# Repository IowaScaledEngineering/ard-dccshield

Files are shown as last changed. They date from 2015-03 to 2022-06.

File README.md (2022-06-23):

# About the ARD-DCCSHIELD

The ARD-DCCSHIELD is an optoisolated interface shield for connecting an Arduino to a model railroad DCC control system.  Additionally, the board has provisions for connecting I2C accessories and general purpose I/O lines, as well as optionally (jumper selectably) powering the Arduino off of DCC power and providing up to 400mA of 5VDC to connected circuitry.

The board is designed to be compatible with various DCC decoder libraries and Arduino boards.  We typically use [Alex Shepherd's excellent NmraDcc library](https://github.com/mrrwa/NmraDcc/).  

The ARD-DCCSHIELD was designed by Nathan Holmes (maverick /at/ drgw.net) and Michael Petersen (railfan /at/ drgw.net).  The ARD-DCCSHIELD is open hardware, meaning that anyone is welcome to make their own or change/improve upon our design to meet their needs.  Please refer to the hardware and software license files in this repository for details.

For those not wanting to build their own, the boards are [available for purchase](http://www.iascaled.com/store/ARD-DCCSHIELD) from Iowa Scaled Engineering.

## Features

* Convenient way to interface standard Arduinos with DCC track signals, in order to build custom decoders
* Can route DCC signal to D2, D3, or D7 as an input, depending on the needs of the host processor
* Provides complete electrical isolation between the track and your Arduino/computer (if not powered off DCC)
* Can provide up to 500mA of 5V DC power off the DCC track signal
* Provides handy Qwiic-compatible I2C port for connecting more peripherals (v2.x only)
* Provides 8-position terminal block for connecting to Arduino I/O lines

## Getting Started

At the bare minimum, you'll need to:
 * Have a working knowledge of electronics and programming.  The ARD-DCCSHIELD is a building block that provides an electrical interface between an Arduino and the DCC track signal, not a complete decoder.
 * Connect DCC track voltage should be connected to the DCC connector, a blue two-pin terminal block at the bottom of the board (J7 on v1.x boards, J6 on v2.x)
 * Configure the board to route the DCC signal to the appropriate Arduino digital I/O pin (D2, D3, or D7).  With v1.x boards, this was done using JP4 and possibly JP2, pins 1-2).  With v2.x boards, this just involves flipping one of the DIP switches (SW1, switches 3-5) to "ON" matching the pin you want to route the signal into.
 * Provide power to the Arduino or configure the DCCSHIELD to power things off of DCC (JP5 on v1.x boards, the small slide switch SW2 on v2.x boards).

You'll also probably need to [install an Arduino library](https://www.arduino.cc/en/Guide/Libraries) to decode the DCC signal, unless you intend to write your own.

If all is good, you'll get both a green and an amber LED glowing on the shield.

When in doubt, please refer to the schematic.  The source files are in gEDA format, but there are PDFs of the production version schematics under the pg/ directory.  Just pick the version that corresponds to your PCB version and open the "ard-dccshield.pdf" file.

 * [v1.0 Schematic](https://github.com/IowaScaledEngineering/ard-dccshield/raw/master/pg/ard-dccshield-v1.0-ba9ec04/ard-dccshield.pdf)
 * [v1.1 Schematic](https://github.com/IowaScaledEngineering/ard-dccshield/raw/master/pg/ard-dccshield-v1.1-f6d6da8/ard-dccshield.pdf)
 * [v1.2 Schematic](https://github.com/IowaScaledEngineering/ard-dccshield/raw/master/pg/ard-dccshield-v1.2-2bd1af7/ard-dccshield.pdf)
 * [v1.3 Schematic](https://github.com/IowaScaledEngineering/ard-dccshield/raw/master/pg/ard-dccshield-v1.3-e23d249/ard-dccshield.pdf)
 * [v2.0 Schematic](https://github.com/IowaScaledEngineering/ard-dccshield/raw/master/pg/ard-dccshield-v2.0-4f6f1bd/ard-dccshield.pdf)

## Indicators

### D1 - Amber LED
The amber LED indicates that a signal is present on J6 (v2.x boards) or J7 (v1.x boards), the DCC input.  If the amber LED does not light, the board is not receiving a signal.

### D2 - Green LED
The green LED indicates that the ARD-DCCSHIELD is correctly powered.  If this light does not come on, check that either the Arduino is getting power from an external source or that the power switch SW2 (v2.x boards) or JP5 (v1.x boards)is set correctly.

## Connectors - Version 2.x Boards ONLY

*Version 2.x is the most recent revision of the ARD-DCCSHIELD.  All boards shipped by ISE after 6/15/2022 will be version 2.0 or later.*

### J1/J2 - Standard Rev 3 Arduino Headers

These are the big pin headers that connect the shield through to an Arduino.  

For some early Arduinos (pre-R3 pinout), you'll notice that the topmost pins (N/C, VIO, RST, 3.3V on J1, SCL, SDA, AREF, and GND on J2) do not connect.  See the JP6 entry in the Configuration section below for details on what you'll need to do.

### J3 - Holes for Arduino SPI

If you need to pass the 6-pin ICSP/SPI header through the ARD-DCCSHIELD to some other shield above it, we've left holes in the right spot.  You'll need to solder in an appropriate 2x3 pin header - see the bill of materials for a suggested Samtec part number.  These holes are not connected to anything on the ARD-DCCSHIELD.

### J4 - Digital I/O Terminal Block

Since most folks are going to decode a DCC signal to then trigger some other hardware, we've provided terminal blocks for eight of the Arduino I/O pins.  These connect to the digital I/O corresponding to the label except for D14, which connects to A0.

### J5 - Power and VIO

Most external hardware is going to need access to power and ground.  J5 provides access to the Arduino +5V line, ground, and VIO (the Arduino's native I/O voltage).

### J6 - DCC Input

This 2-position blue terminal block expects a DCC signal in the range of track voltage (9-22V).  Depending on track voltage, this will present a 9-20mA load to your booster.

### J7 - Qwiic-Compatible I2C Port

This connector is compatible with [SparkFun's Qwiic connector standard](https://www.sparkfun.com/qwiic) for I2C peripherals.  The signals here have been level-shifted to 3.3V for compatibility.  If you want to use an I2C peripheral operating at the Arduino's native VIO (5V with most AVR-based Arduinos, 3.3V with most ARM-based Arduinos), tap the signals out of J8 instead.

### J8 - Alternate 4-Pin I2C

This connector provides an alternate pinout for I2C connections.   These pins are ***not*** level shifted, and operate at the native VIO voltage of the Arduino (5V with most AVR-based Arduinos, 3.3V with most ARM-based Arduinos).

## Configuration - Version 2.x Boards ONLY

### SW1 - Configuration DIP Switch
* Switch 1 does nothing (not connected)
* Switch 2 connects the DCC acknowledgement current pulse generator (ACK) circuit to Arduino pin A1 if switched on.  This will allow the shield to emit a 60mA DCC programming acknowledgement pulse when pin A1 is set high.  The ACK circuit is not designed to operate continually, but only for the ~6 millisecond pulses needed for generating ACKs.  While it should protect itself, U4 and R8 will become quite hot if A1 remains high for significant lengths of time.  If left off, it will disable the ACK generator. 
* Switch 3 routes the incoming DCC signal to Arduino pin D2 if on
* Switch 4 routes the incoming DCC signal to Arduino pin D3 if on
* Switch 5 routes the incoming DCC signal to Arduino pin D7 if on

### SW2 - Power Supply Selection
If SW2 is set towards "ISOLATED", the Arduino is galvanically isolated from track power and can be safely connected to any other power source.  (In fact, it *must* be powered from some other source.)  This allows it to operate connected to an auxiliary power bus or other such power source that you don't want shorted to track power.

If SW2 is set towards "FROM DCC", the ARD-DCCSHIELD will use an onboard high efficiency DC-DC converter to convert track power into 5V to power the Arduino through the 5V pin, as well as the ARD-DCCSHIELD and any other attached hardware.  The power supply is good for 500mA.  Typically the Arduino and the ARD-DCCSHIELD will need 40-50mA of that, so you can safely power approximately 400mA of additional 5V load off of the regulator as well.

### JP6 - Power Supply Selection

Normally, the ARD-DCCSHIELD gets its power from the VIO pin, so as to be compatible with both 3.3V and 5V Arduino-format boards.  For early Arduino pinouts (now exceedingly rare) that lack a VIO (I/O voltage) pin, there's solder jumper JP6 which shorts the VIO line (which isn't present) to 5V.  You'll need to solder jumper JP6 closed to allow the shield to work correctly.  Just heat the pads and apply a small amount of solder to bridge the two halves.  

*Note:  Once JP6 is shorted, the board will fry any 3.3V Arduino it gets plugged into.  Be very careful.  If you want to use the board with a low voltage Arduino once again, carefully remove the solder bridge with solder braid or similar.*

---
# Documentation for v1.x ARD-DCCSHIELD Boards

*Version 1.x is the first generation of the ARD-DCCSHIELD.  The documentation is preserved here for reference, and will apply to all boards shipped by ISE before 6/15/2022.*

## Configuration - Version 1.x Boards ONLY

### JP1 - I2C Pull-Up Resistors

I2C is an open-collector bus, meaning each node can only pull the line low.  Therefore, both SDA and SCL must be pulled up with resistors to make the bus function.  If you intend to use the I2C connections on the ARD-DCCSHIELD and don't have pull-ups elsewhere, jumper pins 1-2 and 3-4 of JP1 to provide 2k pull-ups on both SDA and SCL.

### JP2 (Pins 1-2) - I2C /IORST

If you need power on the [Iowa Scaled Engineering standard I2C 6p6c (RJ11) connector](https://www.iascaled.com/store/6P6C-I2C), it's typically sent down the /IORST line.  Jumpering pins 1-2 will connect VIO on the Arduino/shield to the /IORST line on the connector (pin 4).  If you don't intend to use I2C or don't need power, leave this jumper open.

Alternately, if you're not using Arduino D7 for your DCC signal (see JP4 configuration below) and want the ability to reset I2C peripherals using this signal, you can tie /IORST to D7 by placing the number between pins 2-3.

### JP3 - I2C /INT and /OE 

The [Iowa Scaled Engineering standard I2C 6p6c (RJ11) connector](https://www.iascaled.com/store/6P6C-I2C) allows for two additional signals: /OE (active low Output Enable) going from the Arduino to the I2C bus; and /INT (active low interrupt), to allow I2C slaves to signal the Arduino they need attention.  Jumper JP3 pins 1-2 to connect /INT to Arduino pin D6 and/or JP3 pins 3-4 to connect /OE to Arduino pin D5.

### JP4 and JP2 (Pins 3-4) - DCC Signal to Arduino Pin

Probably the single most important configuration on the ARD-DCCSHIELD is to select which Arduino pin will receive the DCC signal.  Typically this is going to be a pin that can be conencted to a hardware change interrupt in the code, as edges need to be precisely detected to decode the signal correctly.  To accomodate a wide variety of Arduinos, there are three possible selections:
 * DCC signal to D2 - jumper JP4, pins 3-4
 * DCC signal to D3 - jumper JP4, pins 1-2
 * DCC signal to D7 - jumper JP2, pins 3-4

A complete list of which digital IO lines are available as hardware interrupts is available at the Arduino [attachInterrupt()](https://www.arduino.cc/en/Reference/AttachInterrupt) page.

### JP5 - Arduino Powered from DCC

If JP5 is left un-jumpered, the Arduino is galvanically isolated from track power and can be safely connected to any other power source.  (In fact, it *must* be powered from some other source.)  This allows it to operate connected to an auxilliary power bus or other such power source that you don't want shorted to track power.

If pins 1-2 and 3-4 of JP5 are jumpered, the ARD-DCCSHIELD will use an onboard high efficiency DC-DC converter to convert track power into 5V to power the Arduino, ARD-DCCSHIELD, and any other attached hardware.  The power supply is good for 500mA.  Typically the Arduino and the ARD-DCCSHIELD will need 40-50mA of that, so you can safely power approximately 400mA of additional 5V load off of the regulator as well.

### JP6 - Boards without VIO

Normally, the ARD-DCCSHIELD gets its power from the VIO pin, so as to be compatible with both 3.3V and 5V Arduino-format boards.  For early Arduino pinouts that lack a VIO (I/O voltage) pin, there's solder jumper JP6 which shorts the VIO line (which isn't present) to 5V.  You'll need to solder jumper JP6 closed to allow the shield to work correctly.  Just heat the pads and apply a small amount of solder to bridge the two halves.  

*Note:  Once JP6 is shorted, the board will fry any 3.3V Arduino it gets plugged into.  Be very careful.  If you want to use the board with a low voltage Arduino once again, carefully remove the solder bridge with solder braid or similar.*

### JP7 - Enable Programming ACK

Jumpering pins 1-2 & 3-4 of JP7 will allow the shield to emit a 60mA DCC programming acknowledgement pulse when pin .  The ACK circuit is connected to Arduino pin A1, and will generate an ACK current pulse when A1 is set high.  The ACK circuit is not designed to operate continually, but only for the ~6 millisecond pulses needed for generating ACKs.  While it should protect itself, U4 and R8 will become quite hot if A1 remains high for significant lengths of time.

## Connectors - Version 1.x Boards ONLY

*Version 1.x is the first generation of the ARD-DCCSHIELD.  The documentation is preserved here for reference, and will apply to all boards shipped by ISE before 6/15/2022.*

### J1/J2 - Standard Rev 3 Arduino Headers

These are the big pin headers that connect the shield through to an Arduino.  

For some early Arduinos, you'll notice that the topmost pins (N/C, VIO, RST, 3.3V on J1, SCL, SDA, AREF, and GND on J2) do not connect.  See the JP6 entry in the Configuration section below for details on what you'll need to do.

### J3 - Holes for Arduino SPI

If you need to pass the 6-pin ICSP/SPI header through the ARD-DCCSHIELD to some other shield above it, we've left holes in the right spot.  You'll need to solder in an appropriate 2x3 pin header - see the bill of materials for a suggested Samtec part number.  These holes are not connected to anything on the ARD-DCCSHIELD.

### J4 - Digital I/O Terminal Block

Since most folks are going to decode a DCC signal to then trigger some other hardware, we've provided terminal blocks for eight of the Arduino I/O pins.  These connect to the digital I/O corresponding to the label except for D14, which connects to A0.

### J5 - Power and VIO

Most external hardware is going to need access to power and ground.  J5 provides access to the Arduino +5V line, ground, and VIO (the Arduino's native I/O voltage).

### J6 - ISE Standard 6p6c I2C 

This is an [Iowa Scaled Engineering standard I2C 6p6c (RJ11) connector](https://www.iascaled.com/store/6P6C-I2C), which can be used to connect to a number of ISE I2C peripheral boards.  It provides a handy modular plug for the I2C bus.

### J7 - DCC Input

This expects a DCC signal in the range of track voltage (9-22V).  Depending on track voltage, this will present a 9-20mA load to your booster.

### J8 - Alternate 4-Pin I2C

This connector provides an alternate pinout for I2C connections. 
*Note:  On rev 1.1 of the PCB, the SDA and SCL silkscreen markings are reversed.*

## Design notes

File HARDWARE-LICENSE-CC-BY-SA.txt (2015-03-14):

The hardware design files for the Iowa Scaled Engineering ARD-DCCSHIELD are
open hardware, and licensed under the Creative Commons Attribution-Share
Alike license.

A copy can be found below, or from 
  http://creativecommons.org/licenses/by-sa/4.0/legalcode
-----------------------------------------------------------------------------

Creative Commons Attribution-ShareAlike 4.0 International Public License

By exercising the Licensed Rights (defined below), You accept and agree to
be bound by the terms and conditions of this Creative Commons
Attribution-ShareAlike 4.0 International Public License ("Public License").
To the extent this Public License may be interpreted as a contract, You are
granted the Licensed Rights in consideration of Your acceptance of these
terms and conditions, and the Licensor grants You such rights in
consideration of benefits the Licensor receives from making the Licensed
Material available under these terms and conditions.

Section 1 – Definitions.

    Adapted Material means material subject to Copyright and Similar Rights
that is derived from or based upon the Licensed Material and in which the
Licensed Material is translated, altered, arranged, transformed, or
otherwise modified in a manner requiring permission under the Copyright and
Similar Rights held by the Licensor. For purposes of this Public License,
where the Licensed Material is a musical work, performance, or sound
recording, Adapted Material is always produced where the Licensed Material
is synched in timed relation with a moving image.
    Adapter's License means the license You apply to Your Copyright and
Similar Rights in Your contributions to Adapted Material in accordance with
the terms and conditions of this Public License.
    BY-SA Compatible License means a license listed at
creativecommons.org/compatiblelicenses, approved by Creative Commons as
essentially the equivalent of this Public License.
    Copyright and Similar Rights means copyright and/or similar rights
closely related to copyright including, without limitation, performance,
broadcast, sound recording, and Sui Generis Database Rights, without regard
to how the rights are labeled or categorized. For purposes of this Public
License, the rights specified in Section 2(b)(1)-(2) are not Copyright and
Similar Rights.
    Effective Technological Measures means those measures that, in the
absence of proper authority, may not be circumvented under laws fulfilling
obligations under Article 11 of the WIPO Copyright Treaty adopted on
December 20, 1996, and/or similar international agreements.
    Exceptions and Limitations means fair use, fair dealing, and/or any
other exception or limitation to Copyright and Similar Rights that applies
to Your use of the Licensed Material.
    License Elements means the license attributes listed in the name of a
Creative Commons Public License. The License Elements of this Public License
are Attribution and ShareAlike.
    Licensed Material means the artistic or literary work, database, or
other material to which the Licensor applied this Public License.
    Licensed Rights means the rights granted to You subject to the terms and
conditions of this Public License, which are limited to all Copyright and
Similar Rights that apply to Your use of the Licensed Material and that the
Licensor has authority to license.
    Licensor means the individual(s) or entity(ies) granting rights under
this Public License.
    Share means to provide material to the public by any means or process
that requires permission under the Licensed Rights, such as reproduction,
public display, public performance, distribution, dissemination,
communication, or importation, and to make material available to the public
including in ways that members of the public may access the material from a
place and at a time individually chosen by them.
    Sui Generis Database Rights means rights other than copyright resulting
from Directive 96/9/EC of the European Parliament and of the Council of 11
March 1996 on the legal protection of databases, as amended and/or
succeeded, as well as other essentially equivalent rights anywhere in the
world.
    You means the individual or entity exercising the Licensed Rights under
this Public License. Your has a corresponding meaning.

Section 2 – Scope.

    License grant.
        Subject to the terms and conditions of this Public License, the
Licensor hereby grants You a worldwide, royalty-free, non-sublicensable,
non-exclusive, irrevocable license to exercise the Licensed Rights in the
Licensed Material to:
            reproduce and Share the Licensed Material, in whole or in part;
and
            produce, reproduce, and Share Adapted Material.
        Exceptions and Limitations. For the avoidance of doubt, where
Exceptions and Limitations apply to Your use, this Public License does not
apply, and You do not need to comply with its terms and conditions.
        Term. The term of this Public License is specified in Section 6(a).
        Media and formats; technical modifications allowed. The Licensor
authorizes You to exercise the Licensed Rights in all media and formats
whether now known or hereafter created, and to make technical modifications
necessary to do so. The Licensor waives and/or agrees not to assert any
right or authority to forbid You from making technical modifications
necessary to exercise the Licensed Rights, including technical modifications
necessary to circumvent Effective Technological Measures. For purposes of
this Public License, simply making modifications authorized by this Section
2(a)(4) never produces Adapted Material.
        Downstream recipients.
            Offer from the Licensor – Licensed Material. Every recipient of
the Licensed Material automatically receives an offer from the Licensor to
exercise the Licensed Rights under the terms and conditions of this Public
License.
            Additional offer from the Licensor – Adapted Material. Every
recipient of Adapted Material from You automatically receives an offer from
the Licensor to exercise the Licensed Rights in the Adapted Material under
the conditions of the Adapter’s License You apply.
            No downstream restrictions. You may not offer or impose any
additional or different terms or conditions on, or apply any Effective
Technological Measures to, the Licensed Material if doing so restricts
exercise of the Licensed Rights by any recipient of the Licensed Material.
        No endorsement. Nothing in this Public License constitutes or may be
construed as permission to assert or imply that You are, or that Your use of
the Licensed Material is, connected with, or sponsored, endorsed, or granted
official status by, the Licensor or others designated to receive attribution
as provided in Section 3(a)(1)(A)(i).

    Other rights.
        Moral rights, such as the right of integrity, are not licensed under
this Public License, nor are publicity, privacy, and/or other similar
personality rights; however, to the extent possible, the Licensor waives
and/or agrees not to assert any such rights held by the Licensor to the
limited extent necessary to allow You to exercise the Licensed Rights, but
not otherwise.
        Patent and trademark rights are not licensed under this Public
License.
        To the extent possible, the Licensor waives any right to collect
royalties from You for the exercise of the Licensed Rights, whether directly
or through a collecting society under any voluntary or waivable statutory or
compulsory licensing scheme. In all other cases the Licensor expressly
reserves any right to collect such royalties.

Section 3 – License Conditions.

Your exercise of the Licensed Rights is expressly made subject to the
following conditions.

    Attribution.

        If You Share the Licensed Material (including in modified form), You
must:
            retain the following if it is supplied by the Licensor with the
Licensed Material:
                identification of the creator(s) of the Licensed Material
and any others designated to receive attribution, in any reasonable manner
requested by the Licensor (including by pseudonym if designated);
                a copyright notice;
                a notice that refers to this Public License;
                a notice that refers to the disclaimer of warranties;
                a URI or hyperlink to the Licensed Material to the extent
                reasonably practicable;
            indicate if You modified the Licensed Material and retain an
indication of any previous modifications; and
            indicate the Licensed Material is licensed under this Public
License, and include the text of, or the URI or hyperlink to, this Public
License.
        You may satisfy the conditions in Section 3(a)(1) in any reasonable
manner based on the medium, means, and context in which You Share the
Licensed Material. For example, it may be reasonable to satisfy the
conditions by providing a URI or hyperlink to a resource that includes the
required information.
        If requested by the Licensor, You must remove any of the information
required by Section 3(a)(1)(A) to the extent reasonably practicable.
    ShareAlike.

    In addition to the conditions in Section 3(a), if You Share Adapted
Material You produce, the following conditions also apply.
        The Adapter’s License You apply must be a Creative Commons license
with the same License Elements, this version or later, or a BY-SA Compatible
License.
        You must include the text of, or the URI or hyperlink to, the
Adapter's License You apply. You may satisfy this condition in any
reasonable manner based on the medium, means, and context in which You Share
Adapted Material.
        You may not offer or impose any additional or different terms or
conditions on, or apply any Effective Technological Measures to, Adapted
Material that restrict exercise of the rights granted under the Adapter's
License You apply.

Section 4 – Sui Generis Database Rights.

Where the Licensed Rights include Sui Generis Database Rights that apply to
Your use of the Licensed Material:

    for the avoidance of doubt, Section 2(a)(1) grants You the right to
extract, reuse, reproduce, and Share all or a substantial portion of the
contents of the database;
    if You include all or a substantial portion of the database contents in
a database in which You have Sui Generis Database Rights, then the database
in which You have Sui Generis Database Rights (but not its individual
contents) is Adapted Material, including for purposes of Section 3(b); and
    You must comply with the conditions in Section 3(a) if You Share all or
a substantial portion of the contents of the database.

For the avoidance of doubt, this Section 4 supplements and does not replace
Your obligations under this Public License where the Licensed Rights include
other Copyright and Similar Rights.

Section 5 – Disclaimer of Warranties and Limitation of Liability.

    Unless otherwise separately undertaken by the Licensor, to the extent
possible, the Licensor offers the Licensed Material as-is and as-available,
and makes no representations or warranties of any kind concerning the
Licensed Material, whether express, implied, statutory, or other. This
includes, without limitation, warranties of title, merchantability, fitness
for a particular purpose, non-infringement, absence of latent or other
defects, accuracy, or the presence or absence of errors, whether or not
known or discoverable. Where disclaimers of warranties are not allowed in
full or in part, this disclaimer may not apply to You.
    To the extent possible, in no event will the Licensor be liable to You
on any legal theory (including, without limitation, negligence) or otherwise
for any direct, special, indirect, incidental, consequential, punitive,
exemplary, or other losses, costs, expenses, or damages arising out of this
Public License or use of the Licensed Material, even if the Licensor has
been advised of the possibility of such losses, costs, expenses, or damages.
Where a limitation of liability is not allowed in full or in part, this
limitation may not apply to You.

    The disclaimer of warranties and limitation of liability provided above
shall be interpreted in a manner that, to the extent possible, most closely
approximates an absolute disclaimer and waiver of all liability.

Section 6 – Term and Termination.

    This Public License applies for the term of the Copyright and Similar
Rights licensed here. However, if You fail to comply with this Public
License, then Your rights under this Public License terminate automatically.

    Where Your right to use the Licensed Material has terminated under
Section 6(a), it reinstates:
        automatically as of the date the violation is cured, provided it is
cured within 30 days of Your discovery of the violation; or
        upon express reinstatement by the Licensor.
    For the avoidance of doubt, this Section 6(b) does not affect any right
the Licensor may have to seek remedies for Your violations of this Public
License.
    For the avoidance of doubt, the Licensor may also offer the Licensed
Material under separate terms or conditions or stop distributing the
Licensed Material at any time; however, doing so will not terminate this
Public License.
    Sections 1, 5, 6, 7, and 8 survive termination of this Public License.

Section 7 – Other Terms and Conditions.

    The Licensor shall not be bound by any additional or different terms or
conditions communicated by You unless expressly agreed.
    Any arrangements, understandings, or agreements regarding the Licensed
Material not stated herein are separate from and independent of the terms
and conditions of this Public License.

Section 8 – Interpretation.

    For the avoidance of doubt, this Public License does not, and shall not
be interpreted to, reduce, limit, restrict, or impose conditions on any use
of the Licensed Material that could lawfully be made without permission
under this Public License.
    To the extent possible, if any provision of this Public License is
deemed unenforceable, it shall be automatically reformed to the minimum
extent necessary to make it enforceable. If the provision cannot be
reformed, it shall be severed from this Public License without affecting the
enforceability of the remaining terms and conditions.
    No term or condition of this Public License will be waived and no
failure to comply consented to unless expressly agreed to by the Licensor.
    Nothing in this Public License constitutes or may be interpreted as a
limitation upon, or waiver of, any privileges and immunities that apply to
the Licensor or You, including from the legal processes of any jurisdiction
or authority.

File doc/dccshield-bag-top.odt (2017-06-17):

Iowa Scaled Engineering, LLC

http://iascaled.com/

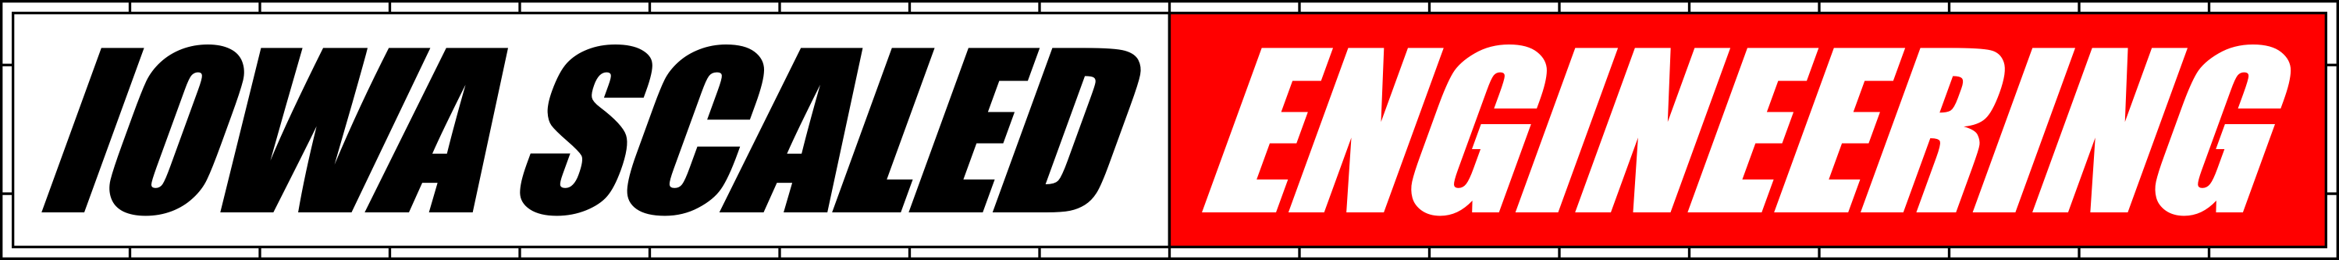
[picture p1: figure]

Arduino DCC Shield

The ARD-DCCSHIELD interfaces an Arduino to a model railroad DCC control system. The board has general purpose I/O lines, an I²C interface, can send DCC ACK pulses, is fully optoisolated, and can power the Arduino from the DCC bus.

ARD-DCCSHIELD

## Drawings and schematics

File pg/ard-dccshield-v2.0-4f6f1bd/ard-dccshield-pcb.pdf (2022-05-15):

# ard-dccshield.pcb

# 1. Table of Contents (This Page) Created on Sat May 14 12:12:09 2022

# 2. component 3. solder 4. outline 5. plated-drill 6. componentmask 7. soldermask 8. topsilk 9. bottomsilk 10. toppaste 11. topassembly 12. bottomassembly 13. fab

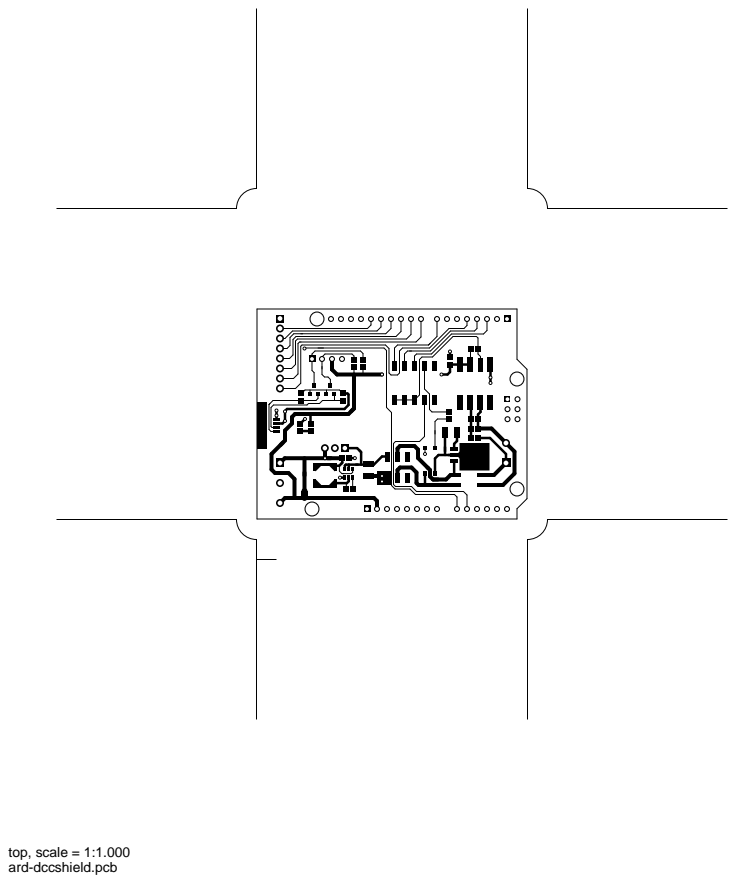
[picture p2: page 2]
top, scale = 1:1.000

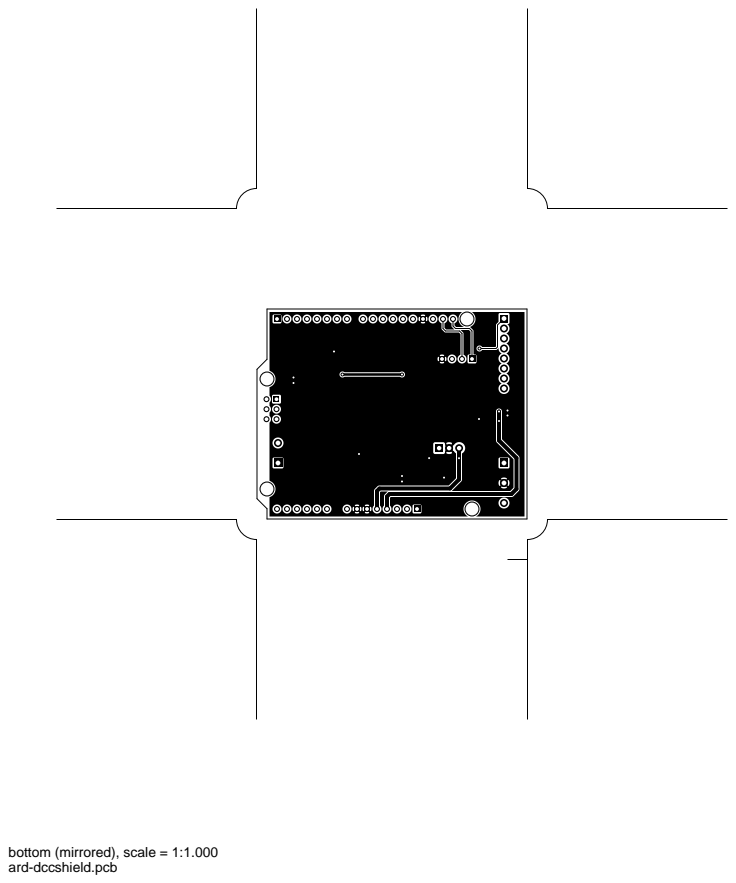
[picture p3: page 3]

bottom (mirrored), scale = 1:1.000

outline, scale = 1:1.000

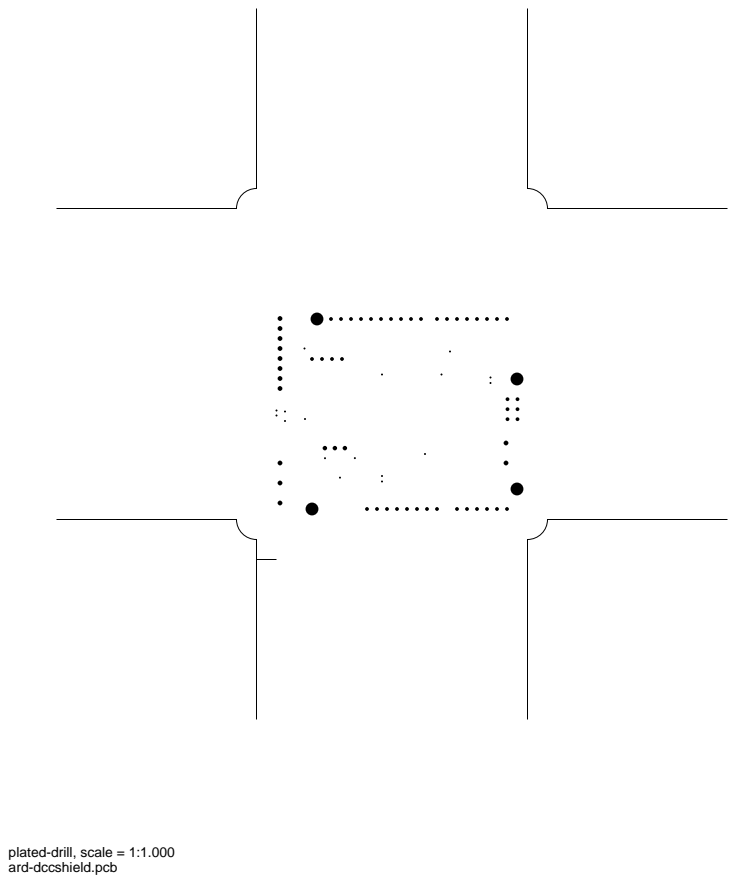
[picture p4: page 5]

plated-drill, scale = 1:1.000

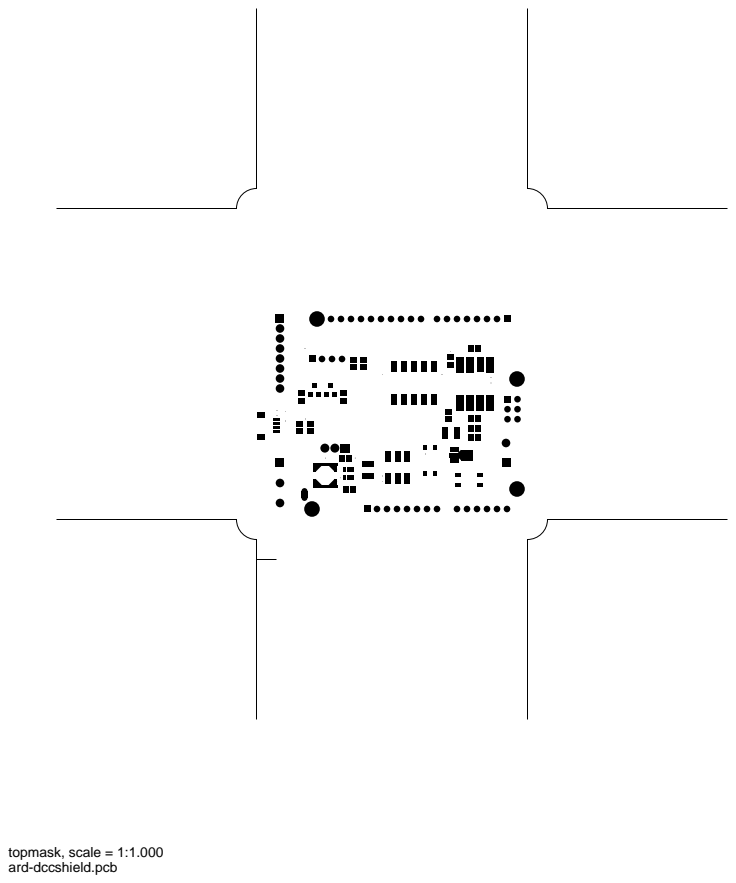
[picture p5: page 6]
topmask, scale = 1:1.000

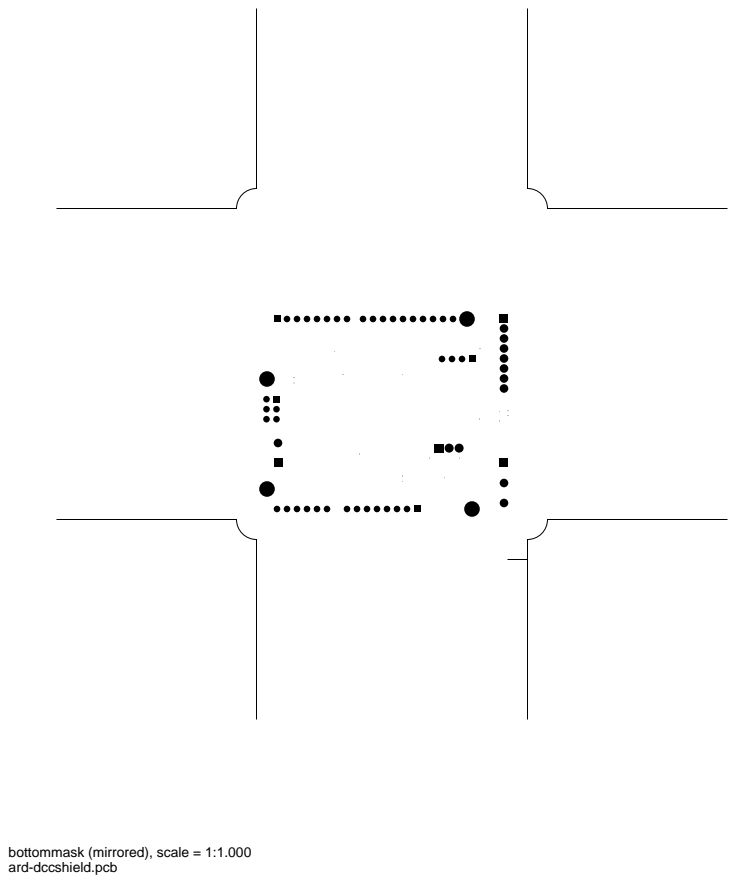
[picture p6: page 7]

bottommask (mirrored), scale = 1:1.000

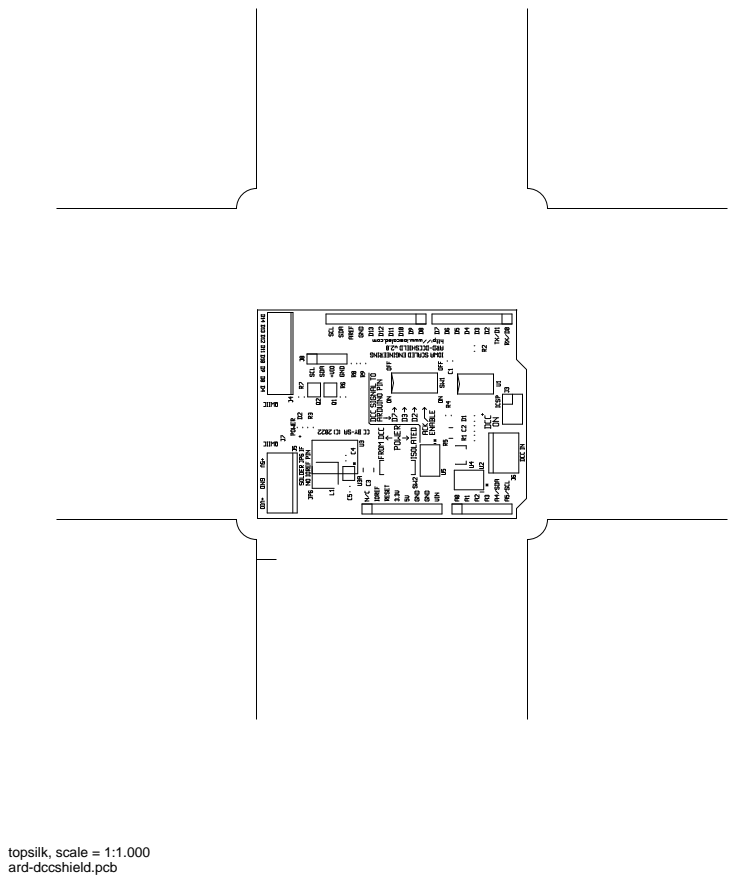
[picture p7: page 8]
topsilk, scale = 1:1.000

bottomsilk (mirrored), scale = 1:1.000

toppaste, scale = 1:1.000

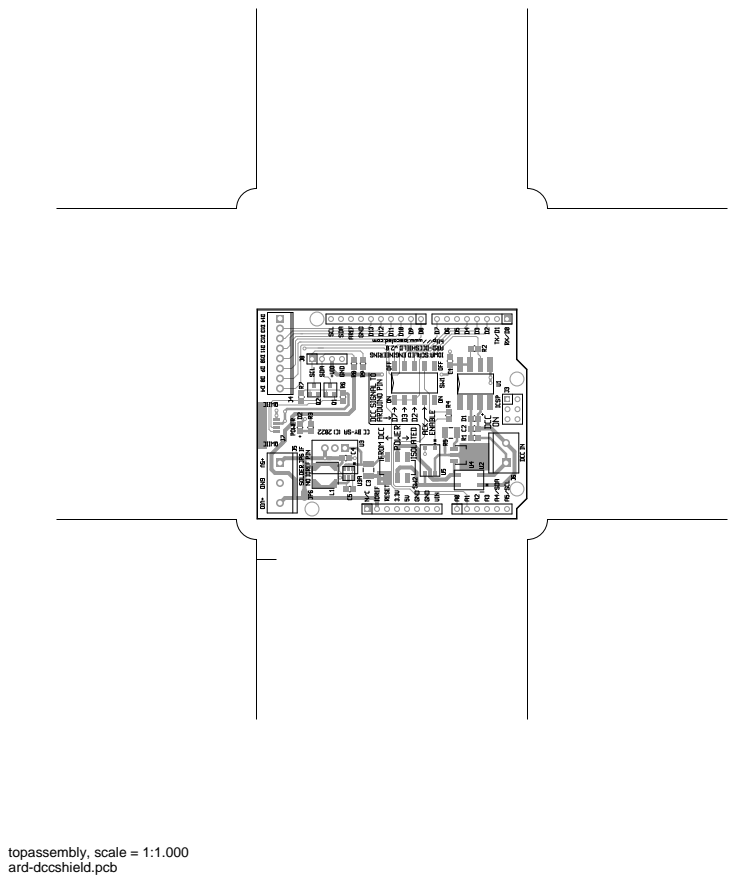
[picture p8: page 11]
topassembly, scale = 1:1.000

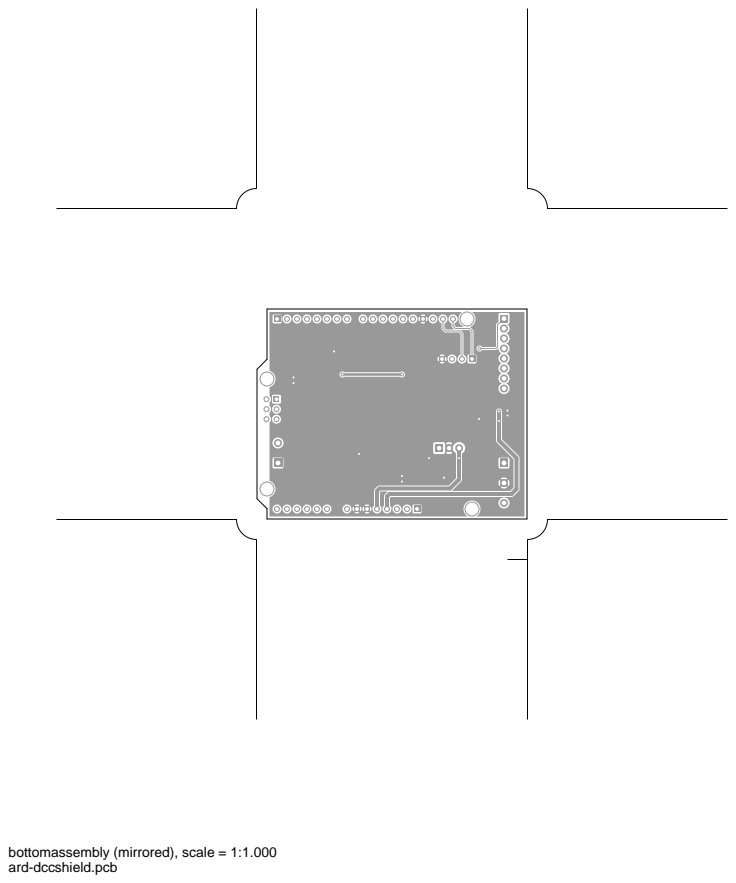
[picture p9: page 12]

bottomassembly (mirrored), scale = 1:1.000

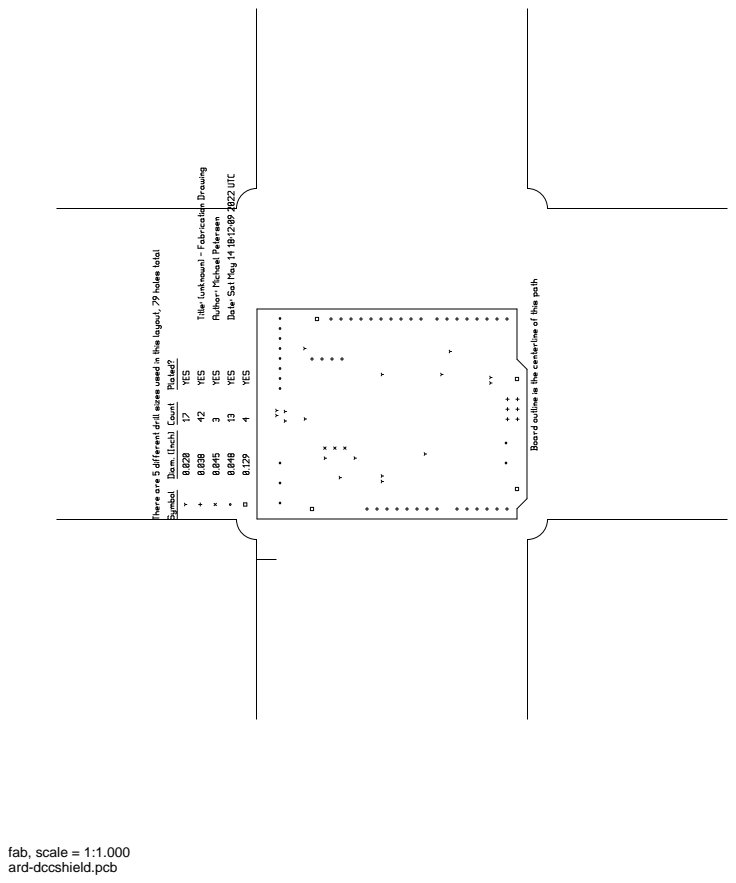
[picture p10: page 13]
fab, scale = 1:1.000

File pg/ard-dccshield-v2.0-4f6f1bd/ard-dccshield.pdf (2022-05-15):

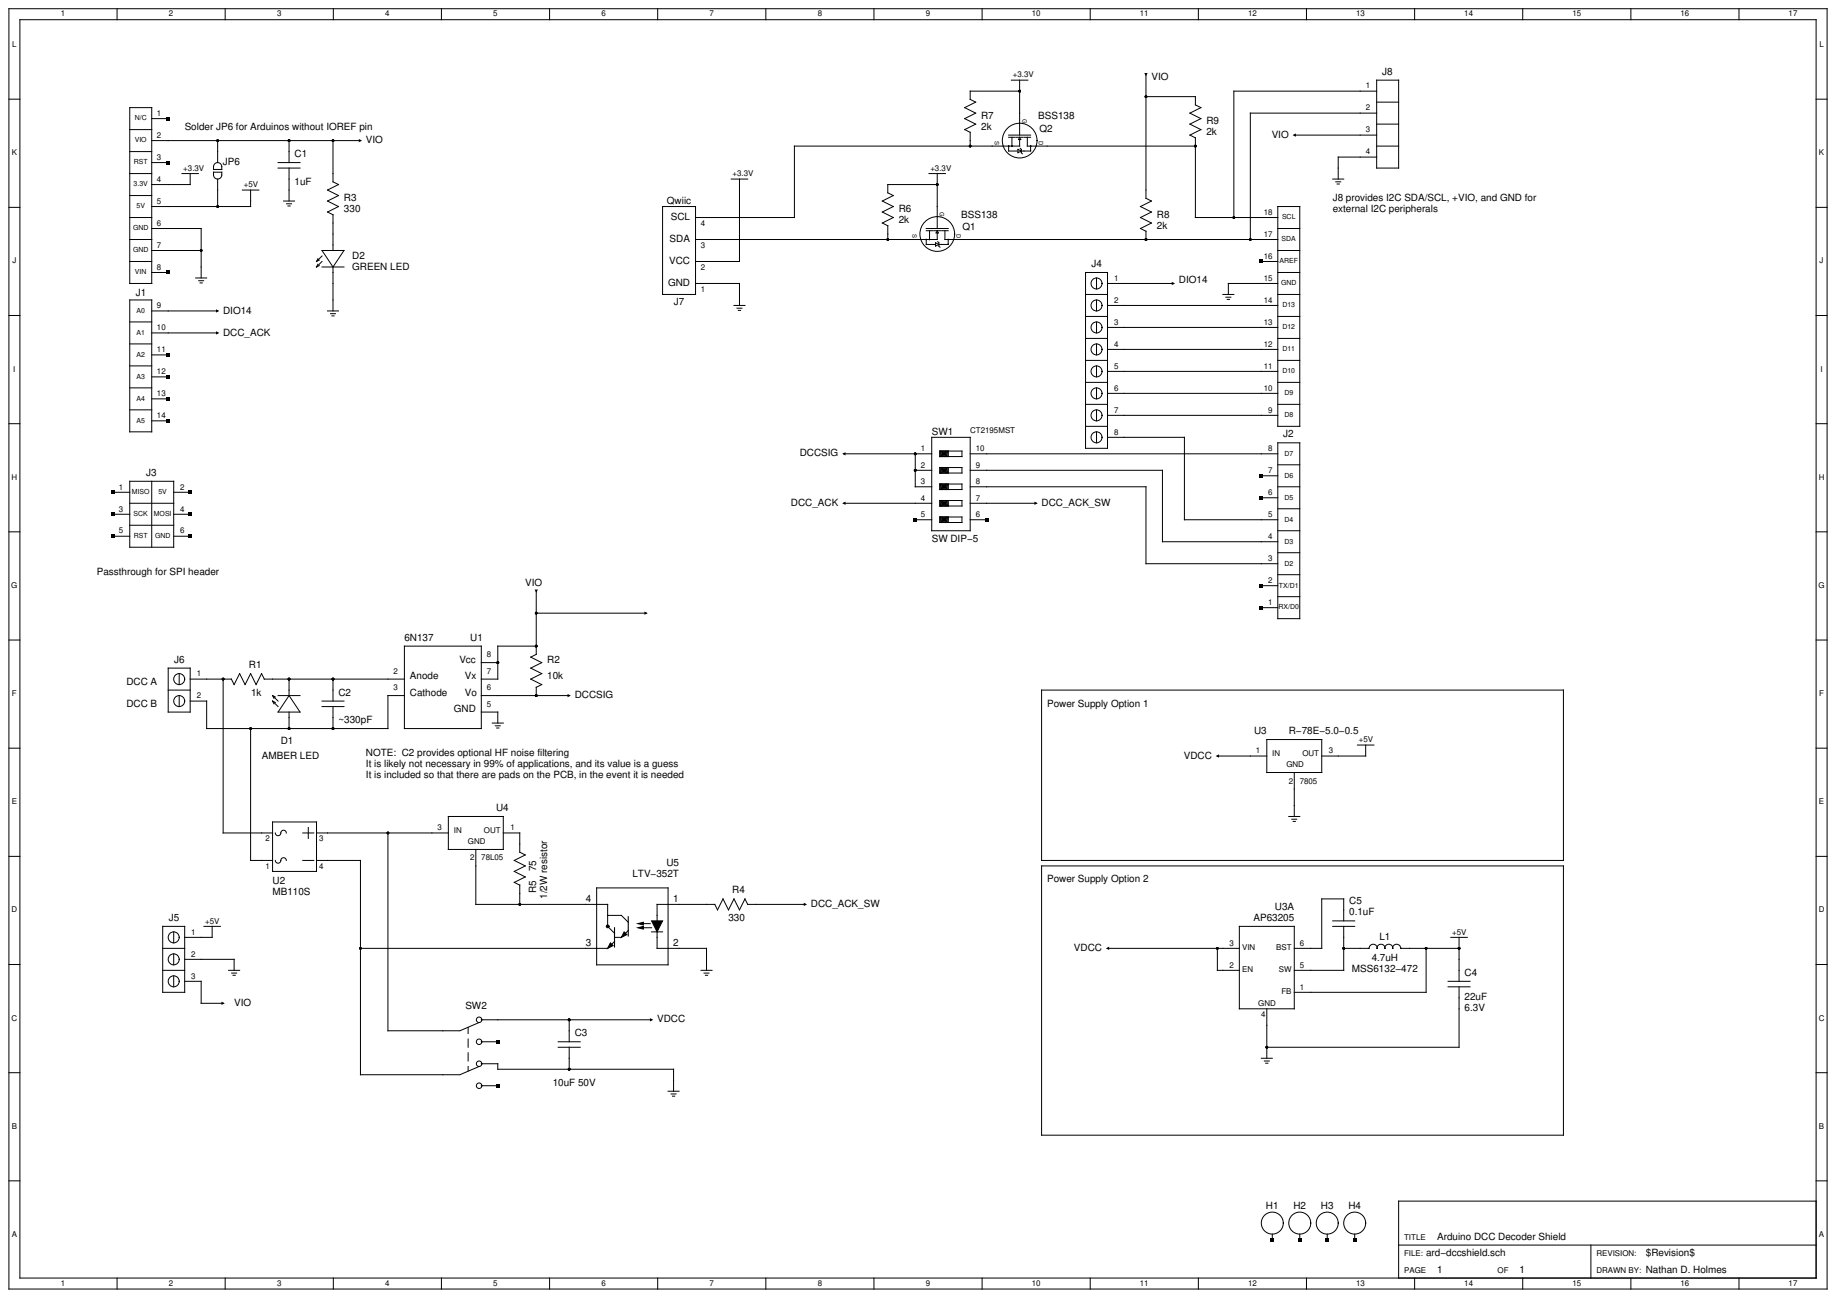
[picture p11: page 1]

Solder JP6 for Arduinos without IOREF pin

J8 provides I2C SDA/SCL, +VIO, and GND for
external I2C peripherals

Passthrough for SPI header

NOTE: C2 provides optional HF noise filtering
It is likely not necessary in 99% of applications, and its value is a guess
It is included so that there are pads on the PCB, in the event it is needed

Power Supply Option 2

Arduino DCC Decoder Shield
ard−dccshield.sch

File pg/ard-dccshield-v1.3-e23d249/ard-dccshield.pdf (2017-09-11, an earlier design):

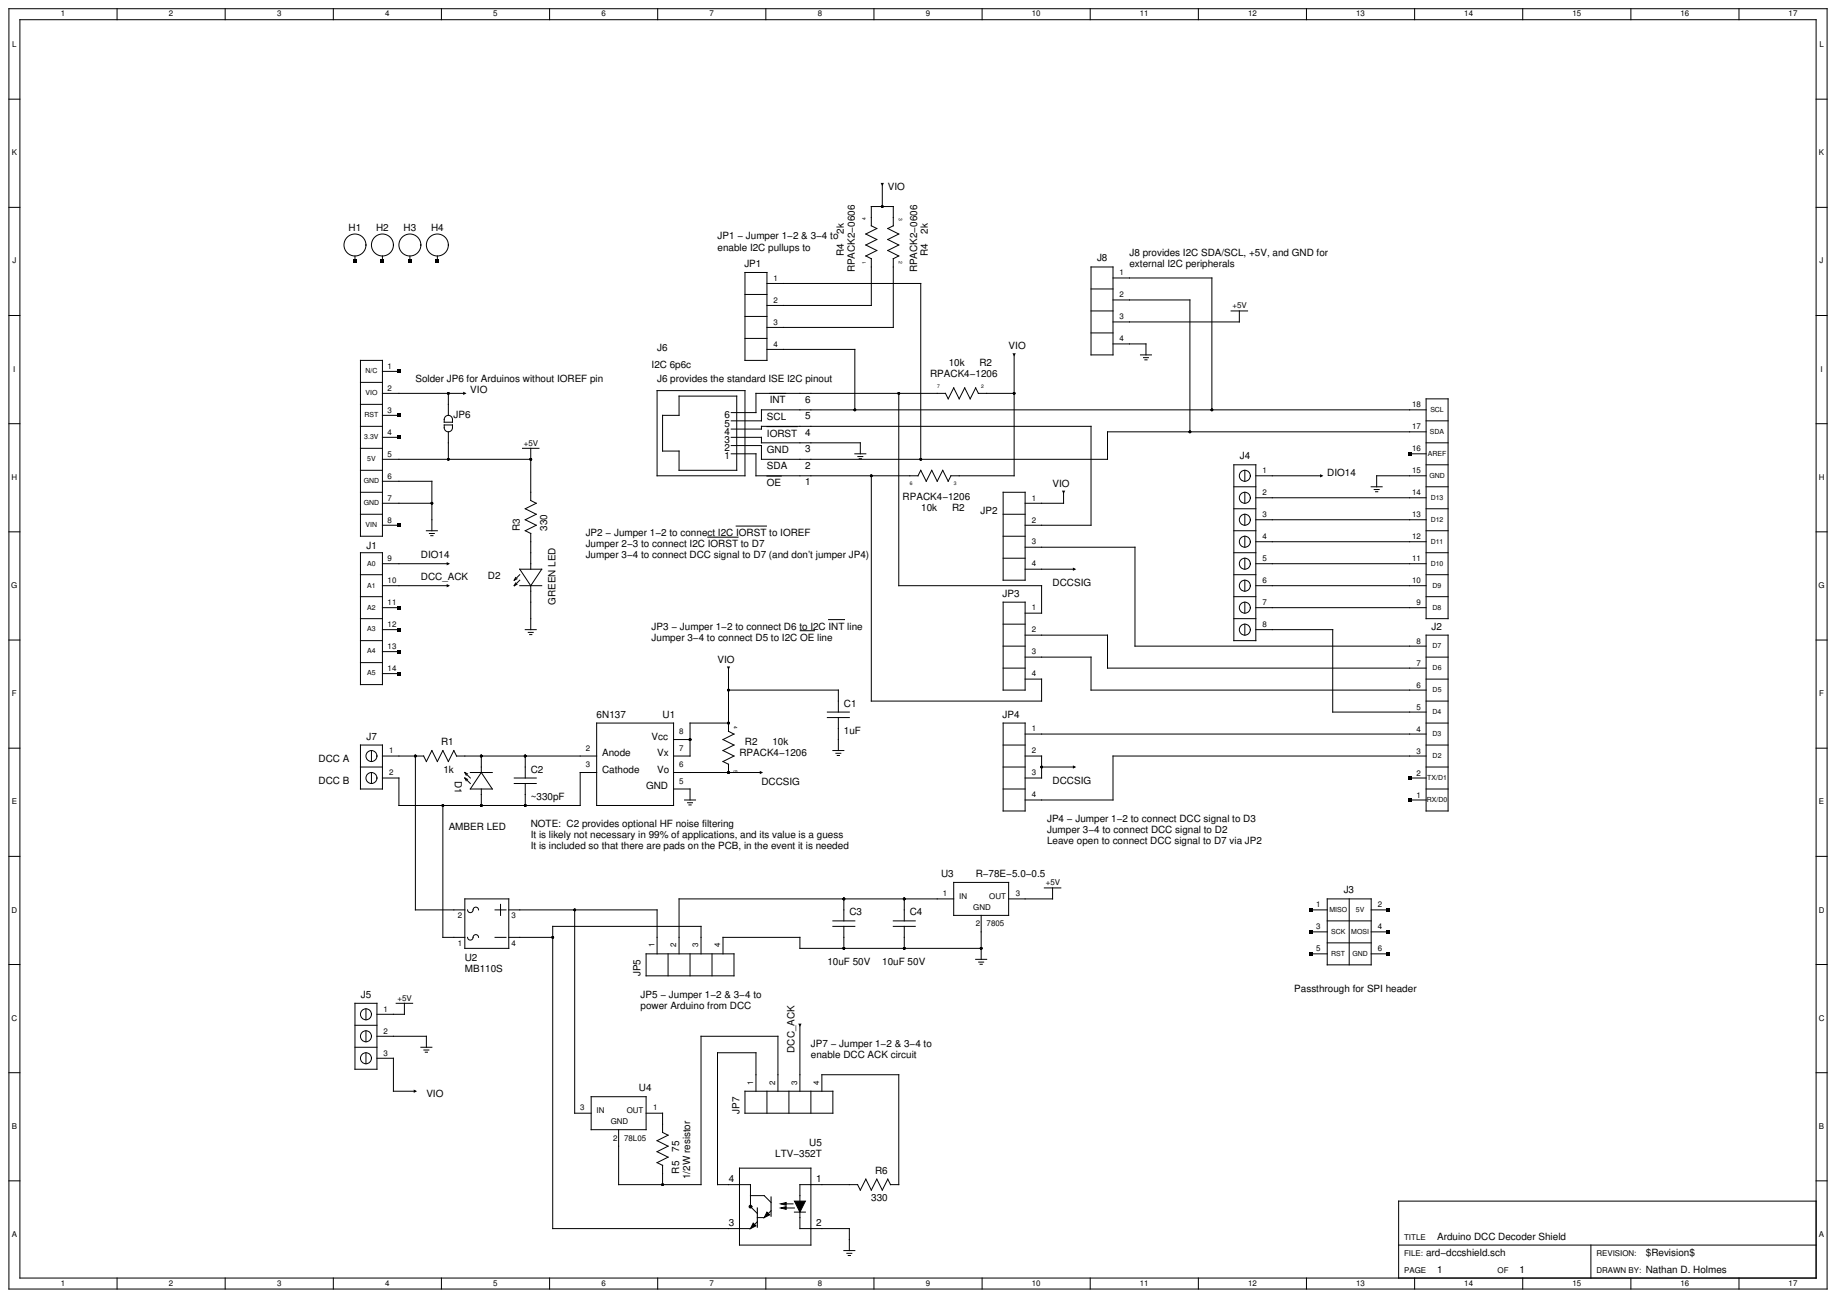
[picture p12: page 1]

J8 provides I2C SDA/SCL, +5V, and GND for
external I2C peripherals

Solder JP6 for Arduinos without IOREF pin

JP2 − Jumper 1−2 to connect I2C IORST to IOREF
Jumper 2−3 to connect I2C IORST to D7
Jumper 3−4 to connect DCC signal to D7 (and don’t jumper JP4)

JP3 − Jumper 1−2 to connect D6 to I2C INT line
Jumper 3−4 to connect D5 to I2C OE line

JP4 − Jumper 1−2 to connect DCC signal to D3
Jumper 3−4 to connect DCC signal to D2
Leave open to connect DCC signal to D7 via JP2

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

JP5 − Jumper 1−2 & 3−4 to
power Arduino from DCC

Passthrough for SPI header

DCC_ACK JP7 − Jumper 1−2 & 3−4 to enable DCC ACK circuit

Arduino DCC Decoder Shield
ard−dccshield.sch

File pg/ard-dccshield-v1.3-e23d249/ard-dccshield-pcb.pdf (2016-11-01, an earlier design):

# ard-dccshield.pcb

# 1. Table of Contents (This Page) Created on Tue Nov 1 11:58:47 2016

# 2. component 3. solder 4. outline 5. plated-drill 6. componentmask 7. soldermask 8. topsilk 9. bottomsilk 10. toppaste 11. topassembly 12. bottomassembly 13. fab

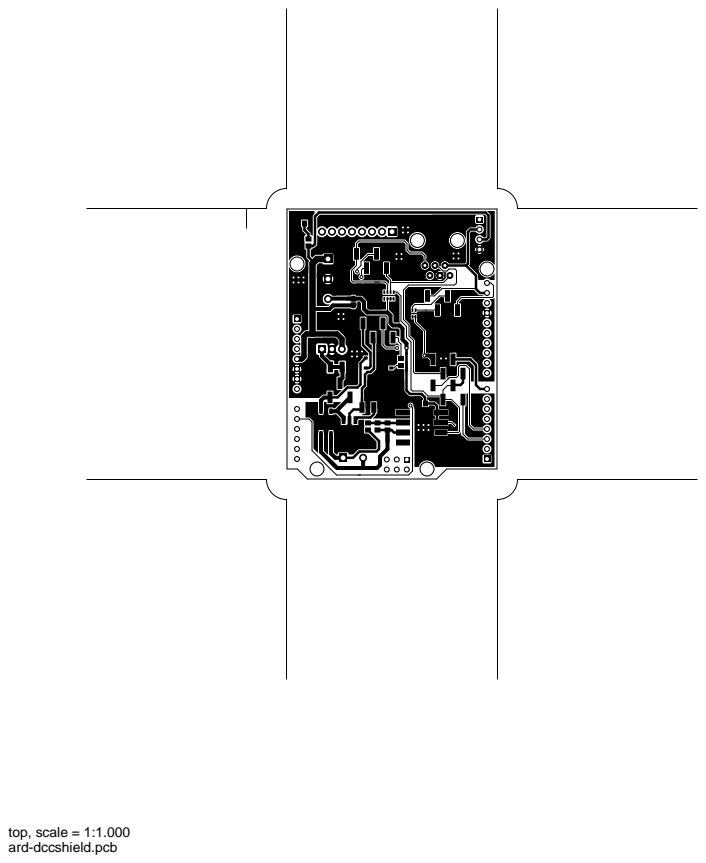
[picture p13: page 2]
top, scale = 1:1.000


bottom (mirrored), scale = 1:1.000

outline, scale = 1:1.000


plated-drill, scale = 1:1.000

topmask, scale = 1:1.000


bottommask (mirrored), scale = 1:1.000

topsilk, scale = 1:1.000


bottomsilk (mirrored), scale = 1:1.000

toppaste, scale = 1:1.000

topassembly, scale = 1:1.000


bottomassembly (mirrored), scale = 1:1.000

fab, scale = 1:1.000

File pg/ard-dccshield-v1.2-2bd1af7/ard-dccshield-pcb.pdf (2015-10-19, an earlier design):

# ard-dccshield.pcb

# 1. Table of Contents (This Page) Created on Mon Oct 19 14:44:36 2015

# 2. component 3. solder 4. outline 5. plated-drill 6. componentmask 7. soldermask 8. topsilk 9. bottomsilk 10. toppaste 11. topassembly 12. bottomassembly 13. fab

top, scale = 1:1.000


bottom (mirrored), scale = 1:1.000

outline, scale = 1:1.000


plated-drill, scale = 1:1.000

topmask, scale = 1:1.000


bottommask (mirrored), scale = 1:1.000

topsilk, scale = 1:1.000


bottomsilk (mirrored), scale = 1:1.000

toppaste, scale = 1:1.000

topassembly, scale = 1:1.000


bottomassembly (mirrored), scale = 1:1.000

fab, scale = 1:1.000

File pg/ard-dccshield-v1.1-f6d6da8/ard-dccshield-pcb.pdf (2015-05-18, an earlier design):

# ard-dccshield.pcb

# 1. Table of Contents (This Page) Created on Mon May 18 15:44:02 2015

# 2. component 3. solder 4. outline 5. plated-drill 6. componentmask 7. soldermask 8. topsilk 9. bottomsilk 10. toppaste 11. topassembly 12. bottomassembly 13. fab

top, scale = 1:1.000


bottom (mirrored), scale = 1:1.000

outline, scale = 1:1.000


plated-drill, scale = 1:1.000

topmask, scale = 1:1.000


bottommask (mirrored), scale = 1:1.000

topsilk, scale = 1:1.000

bottomsilk (mirrored), scale = 1:1.000

toppaste, scale = 1:1.000

topassembly, scale = 1:1.000


bottomassembly (mirrored), scale = 1:1.000

fab, scale = 1:1.000

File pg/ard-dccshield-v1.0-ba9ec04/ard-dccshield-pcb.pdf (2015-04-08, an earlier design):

# ard-dccshield.pcb

# 1. Table of Contents (This Page) Created on Wed Apr 8 10:08:22 2015

# 2. component 3. solder 4. outline 5. plated-drill 6. componentmask 7. soldermask 8. topsilk 9. bottomsilk 10. toppaste 11. topassembly 12. bottomassembly 13. fab

top, scale = 1:1.000


bottom (mirrored), scale = 1:1.000

outline, scale = 1:1.000


plated-drill, scale = 1:1.000

topmask, scale = 1:1.000


bottommask (mirrored), scale = 1:1.000

topsilk, scale = 1:1.000


bottomsilk (mirrored), scale = 1:1.000

toppaste, scale = 1:1.000

topassembly, scale = 1:1.000


bottomassembly (mirrored), scale = 1:1.000

fab, scale = 1:1.000

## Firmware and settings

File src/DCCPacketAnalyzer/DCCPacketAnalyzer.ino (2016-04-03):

#include "util/atomic.h"

// This sketch is designed for an Arduino Uno with the DCC signal attached to digital pin 2

// *****  START USER CONFIGURATION

// DCC_PIN is the Arduino digital input corresponding to where the DCC signal is coming in.
// It must be an external interrupt for whatever platform you're using.
// Pin 2 is recommended for the Uno

#define DCC_PIN  2


// OPTION_RAW_PACKET_DISPLAY set to non-zero pumps packets through as hex strings
// 0 = Human readable decode
// 1 = Hex String in format P:XX XX XX\n

#define OPTION_RAW_PACKET_DISPLAY 1


// OPTION_SHOW_PREAMBLE_BITS set to 1 displays the number of preamble bits sent before the 
// command came through.  It will be displayed as nnn/ (where n = preamble bits) on the beginning
// of each decode line
// 0 = No preamble bit count display
// 1 = Preamble bit count displayed

#define OPTION_SHOW_PREAMBLE_BITS 0


// OPTION_SUPPRESS_IDLE_PKTS set to 1 suppresses the display of IDLE packets on the rails
// These can be highly annoying to sort through, so most folks are going to want this on
// To turn it off and display each idle packet, set this to 0

#define OPTION_SUPPRESS_IDLE_PKTS 1


// *****  END USER CONFIGURATION
// Normally, you won't need to touch anything beyond here

// The Timer0 prescaler is hard-coded in wiring.c 
#define TIMER_PRESCALER 64

// We will use a time period of 80us and not 87us as this gives us a bit more time to do other stuff 
#define DCC_BIT_SAMPLE_PERIOD (F_CPU * 70L / TIMER_PRESCALER / 1000000L)

#if (DCC_BIT_SAMPLE_PERIOD > 254)
#error DCC_BIT_SAMPLE_PERIOD too big, use either larger prescaler or slower processor
#endif
#if (DCC_BIT_SAMPLE_PERIOD < 8)
#error DCC_BIT_SAMPLE_PERIOD too small, use either smaller prescaler or faster processor
#endif


typedef enum
{
  WAIT_PREAMBLE = 0,
  WAIT_START_BIT,
  WAIT_DATA,
  WAIT_END_BIT
} DccRxWaitState;

#define MAX_DCC_MESSAGE_LEN 6    // including XOR-Byte

typedef struct
{
  uint8_t Size;
  uint8_t PreambleBits;
  uint8_t Flags;
  uint8_t Data[MAX_DCC_MESSAGE_LEN];
} DCCPkt ;

#define DCC_PKT_QUEUE_DEPTH 8

typedef struct
{
   volatile uint8_t headIdx;
   volatile uint8_t tailIdx;
   volatile uint8_t full;
   DCCPkt pktBufferArray[DCC_PKT_QUEUE_DEPTH];
} DCCPktQueue;

DCCPktQueue dccq;

// Interrupt handlers and such shamelessly borrowed from Alex Shepherd's NmraDcc library
void ExternalInterruptHandler(void)
{
  OCR0B = TCNT0 + DCC_BIT_SAMPLE_PERIOD ;
  
  TIMSK0 |= (1<<OCIE0B);  // Enable Timer0 Compare Match B Interrupt
  TIFR0  |= (1<<OCF0B);   // Clear  Timer0 Compare Match B Flag 
}

ISR(TIMER0_COMPB_vect)
{
  uint8_t DccBitVal = !digitalRead(DCC_PIN);
  static DccRxWaitState rxState; 
  static uint8_t bitCount = 0;
  static uint8_t tempByte = 0;
  static DCCPkt PacketBuf;
  

  // Disable Timer0 Compare Match B Interrupt
  TIMSK0 &= ~(1<<OCIE0B);

  bitCount++;

  switch( rxState )
  {
    case WAIT_PREAMBLE:
      if( DccBitVal )
      {
        if( bitCount > 10 )
          rxState = WAIT_START_BIT ;
      }
      else
        bitCount = 0 ;
  
      break;
  
    case WAIT_START_BIT:
      if( !DccBitVal )
      {
        rxState = WAIT_DATA ;
        PacketBuf.Size = 0;
        PacketBuf.PreambleBits = 0;
        for(uint8_t i = 0; i< MAX_DCC_MESSAGE_LEN; i++ )
          PacketBuf.Data[i] = 0;
  
        // We now have 1 too many PreambleBits so decrement before copying
        PacketBuf.PreambleBits = bitCount - 1 ;
  
        bitCount = 0 ;
        tempByte = 0 ;
      }
      break;
  
    case WAIT_DATA:
      tempByte <<= 1;
      if( DccBitVal )
        tempByte |= 1 ;
  
      if( bitCount == 8 )
      {
        if( PacketBuf.Size == MAX_DCC_MESSAGE_LEN ) // Packet is too long - abort
        {
          rxState = WAIT_PREAMBLE ;
          bitCount = 0 ;
        }
        else
        {
          rxState = WAIT_END_BIT ;
          PacketBuf.Data[ PacketBuf.Size++ ] = tempByte ;
        }
      }
      break;
  
    case WAIT_END_BIT:
      if( DccBitVal ) // End of packet?
      {
        rxState = WAIT_PREAMBLE ;
        dccPktPush(&dccq, &PacketBuf);
      }
      else  // Get next Byte
        rxState = WAIT_DATA ;
  
      bitCount = 0 ;
      tempByte = 0 ;
  }
}

void dccQueueInitialize(DCCPktQueue* q)
{
   ATOMIC_BLOCK(ATOMIC_RESTORESTATE)
   {
       q->headIdx = q->tailIdx = 0;
       q->full = 0;
       memset(q->pktBufferArray, 0, DCC_PKT_QUEUE_DEPTH * sizeof(DCCPkt));
   }
}

uint8_t dccQueueDepth(DCCPktQueue* q)
{
   uint8_t result = 0;
   if(q->full)
       return(DCC_PKT_QUEUE_DEPTH);

   ATOMIC_BLOCK(ATOMIC_RESTORESTATE)
   {
       result = (uint8_t)(q->headIdx - q->tailIdx) % DCC_PKT_QUEUE_DEPTH;
   }
   return(result);
}

uint8_t dccPktPush(DCCPktQueue* q, DCCPkt* pkt)
{
   uint8_t* pktPtr;
   // If full, bail with a false
   if (q->full)
       return(0);

   memcpy((uint8_t*)&q->pktBufferArray[q->headIdx], (uint8_t*)pkt, sizeof(DCCPkt));

   if( ++q->headIdx >= DCC_PKT_QUEUE_DEPTH )
       q->headIdx = 0;
   ATOMIC_BLOCK(ATOMIC_RESTORESTATE)
   {
       if (q->headIdx == q->tailIdx)
           q->full = 1;
   }
   return(1);
}

uint8_t dccPktPop(DCCPktQueue* q, DCCPkt* pkt)
{
  if (0 == dccQueueDepth(q))
  {
    memset(pkt, 0, sizeof(DCCPkt));
    return(0);
  }
  
  memcpy(pkt, &q->pktBufferArray[q->tailIdx], sizeof(DCCPkt));
  
  ATOMIC_BLOCK(ATOMIC_RESTORESTATE)
  {
    if( ++q->tailIdx >= DCC_PKT_QUEUE_DEPTH )
      q->tailIdx = 0;
    q->full = 0;
  }

  return(1);
}



void setup() 
{
  // put your setup code here, to run once:
  dccQueueInitialize(&dccq);
  TCCR0A &= ~((1<<WGM01)|(1<<WGM00));
  attachInterrupt( digitalPinToInterrupt(DCC_PIN), ExternalInterruptHandler, RISING);
  Serial.begin(115200);
  Serial.print(F("DCC Packet Analyzer v0.1\n"));
  Serial.print(F("----------------------------\n"));
  Serial.print(F("Iowa Scaled Engineering\n"));  
  Serial.print(F("https://github.com/IowaScaledEngineering/DCCPacketAnalyzer\n"));
}

void rawPacketDecode(DCCPkt* pkt)
{
  uint8_t i;
  Serial.print("P:");
  for(i=0; i<pkt->Size; i++)
  {
    char buffer[4];
    sprintf(buffer, "%02X ", pkt->Data[i]);
    Serial.print(buffer);
  }
  Serial.print("\n");
}

void decodeMultifunction(DCCPkt* pkt, uint8_t* data, uint8_t dataSz)
{
  uint8_t d1 = *data;
  uint8_t d2 = (dataSz>1)?(*(data+1)):0;
  uint8_t c;
  uint8_t instructionType = (d1>>5) & 0x07;
  char buffer[32];

  switch (instructionType)
  {
    case 0: // Decoder and Consist Control Instructions
      
      if (0 == (d1 & 0x10))
      {
        // Decoder Control
        switch((d1>>1) & 0x07)
        {
          case 0: // Decoder reset
            if (d1 & 0x01)
              Serial.print(F("HARD RESET\n"));
            else
              Serial.print(F("RESET\n"));
            break;
          
          case 1: // Factory Test
            if (d1 & 0x01)
              Serial.print(F("Factory test ON\n"));
            else
              Serial.print(F("Factory test OFF\n"));
            break;

          case 3: // Set decoder flags
            if (dataSz >= 2)
            {
              switch((d2>>4) & 0x0F)
              {
                case 0:
                  Serial.print(F("CV Access DISABLE\n"));
                  break;
                case 4:
                  Serial.print(F("Decoder Ack DISABLE\n"));
                  break;
                case 5:
                  if (d1 & 0x01)
                    Serial.print(F("& CONSIST "));
                  Serial.print(F("BiDi ENABLE\n"));
                  break;
                case 8:
                  Serial.print(F("BiDi Set Sub="));
                  sprintf(buffer, "%d\n", d2 & 0x07);
                  Serial.print(buffer);
                  break;
                case 9:
                  Serial.print(F("CV Access ENABLE Sub=\n"));
                  sprintf(buffer, "%d\n", d2 & 0x07);
                  Serial.print(buffer);
                  break;
                case 15:
                  Serial.print(F("CV Access ENABLE\n"));
                  break;
                default:
                  rawPacketDecode(pkt);             
                  break;              
              }
            } else {
              Serial.print(F("Malformed Decoder Flag Packet\n"));
            }
            break;

          case 5: // Set advanced addressing
            if (d1 & 0x01)
              Serial.print(F("CV29 Addr EN\n"));
            else
              Serial.print(F("CV29 Addr DIS\n"));
            break;

          case 7: // Set Decoder Ack
            if (d1 & 0x01)
              Serial.print(F("Dcdr Ack EN\n"));
            else
              Serial.print(F("Dcdr Ack DIS\n"));
            break;
          default:
            rawPacketDecode(pkt);                    
            break;
        }
      } else {
        // Consist Control
        if (dataSz >= 2)
        {
          if (d2 !=0)
            Serial.print(F("ADD to "));
          else
            Serial.print(F("RMVD from "));
          sprintf(buffer, "cnst %03d in %s\n", d2 & 0x7F, (d1 & 0x01)?"REV":"FWD");
          Serial.print(buffer);
          
        } else {
          Serial.print(F("Malformed Consist Packet\n"));
        }
      }
      break;

    case 1:  //Advanced operations instructions
      switch(d1 & 0x1F)
      {
         case 31: // 128 step speed
           if (dataSz >=2)
           {
             if (0 == (d2 & 0x7f))
               sprintf(buffer, "%c-STP\n", (d2 & 0x80)?'F':'R');
             else if (1 == (d2 & 0x7F))
               sprintf(buffer, "%c-EST\n", (d2 & 0x80)?'F':'R');
             else
               sprintf(buffer, "%c-%03d\n", (d2 & 0x80)?'F':'R', d2 & 0x7F);
             Serial.print(buffer);
           } else {
            Serial.print(F("Malformed 128-step speed"));
           }
           break;

         case 30: // Restricted speed
           if (dataSz >= 2)
           {
             if (d2 & 80)
              sprintf(buffer, "EN restrd spd - %03d\n", d2 & 0x3F);
             else
              sprintf(buffer, "DIS restrd spd\n");
             Serial.print(buffer);

           } else {
             Serial.print(F("Malformed restricted speed\n"));            
           }

         case 29: // Analog Function Group
           if (dataSz >= 3)
           {
             sprintf(buffer, "AnalogF %03d v=%03d\n", d2, *(data+2));
             Serial.print(buffer);
           }
           else
             Serial.print(F("Malformed analog function\n"));
           break;

         default:
          Serial.print(F("Unknown Advanced Op Pkt\n"));
          break;
      }
      break;
    
    case 2: // Reverse
    case 3: // Forward
      sprintf(buffer, "%c-", (d1 & 0x20)?'F':'R');
      Serial.print(buffer);
  
      if (0 == (d1 & 0x0F))
      {
        sprintf(buffer, "STP FL=%d\n", (d1 & 0x10)?1:0);
      } 
      else if (1 == (d1 & 0x0F))
      {
        sprintf(buffer, "ESP FL=%d\n", (d1 & 0x10)?1:0);
      }
      else
      {
        sprintf(buffer, "%02d/28 %02d/14 FL=%d\n", ((d1&0x0F)<<1) + ((d1&0x10)?1:0), (d1&0x0F), ((d1&0x10)?1:0));
      }
      Serial.print(buffer);
      break;
  
    case 4: // Function Group 1
      Serial.print("FL:");
      Serial.print((d1 & 0x10)?"1":"0");
  
      Serial.print(" F1-F4:");
      for(c=0x01; c<0x10; c<<=1)
      {
        Serial.print((c & d1)?"1":"0");
      }
      Serial.print("\n");
      break;
  
    case 5: // Function Group 2 / 3
      if (d1 & 0x10)
      {
        Serial.print("F5-F8:");
      } else {
        Serial.print("F9-F12:");
      }
      for(c=0x01; c<0x10; c=c<<1)
      {
        Serial.print((c & d1)?"1":"0");
      }
      Serial.print("\n");
      break;
  
    default:
      rawPacketDecode(pkt);
      break;
  }
}


void loop() 
{
  // put your main code here, to run repeatedly:
  if (dccQueueDepth(&dccq))
  {
    DCCPkt pkt;
    char buffer[32];    
    uint8_t i;
    uint8_t crc;
    dccPktPop(&dccq, &pkt);

    // First, check the CRC
    crc = 0;
    for (i=0; i<pkt.Size-1; i++)
    {
        crc ^= pkt.Data[i];
    }

    if (crc != pkt.Data[pkt.Size-1])
    {
      if (OPTION_SHOW_PREAMBLE_BITS != 0)
      {
        sprintf(buffer, "%03d/", pkt.PreambleBits);
        Serial.print(buffer);
      }


      sprintf(buffer, "E%02d: CRC ", pkt.PreambleBits);
      Serial.print(buffer);
      for(i=0; i<pkt.Size; i++)
      {
        char buffer[4];
        sprintf(buffer, "%02X ", pkt.Data[i]);
        Serial.print(buffer);
      }
      Serial.print("\n");

    }
    else if (0xFF == pkt.Data[0] && 0 == pkt.Data[1])
    {
      // Do nothing
      if(! OPTION_SUPPRESS_IDLE_PKTS)
      {
        if (OPTION_SHOW_PREAMBLE_BITS != 0)
        {
          sprintf(buffer, "%03d/", pkt.PreambleBits);
          Serial.print(buffer);
        }

        switch(OPTION_RAW_PACKET_DISPLAY)
        {
          case 0:
            Serial.print(F("IDLE"));
            break;
          case 1:
            rawPacketDecode(&pkt);
            break;
          default:
            break;
        }
      }

      
    }
    else
    {
      switch(OPTION_RAW_PACKET_DISPLAY)
      {
        case 1:
          rawPacketDecode(&pkt);
          break;        
        default:

          if (OPTION_SHOW_PREAMBLE_BITS != 0)
          {
            sprintf(buffer, "%03d/", pkt.PreambleBits);
            Serial.print(buffer);
          }
    
          if (0 == pkt.Data[0])
          {
            // Multi-function broadcast address
            Serial.print(F("L:*ALL* "));
          }
          else if (0xFF == pkt.Data[0])
          {
              // Idles should have been handled above - this one's malformed
            Serial.print(F("E:Malformed IDLE"));
          }
          else if (1 <= pkt.Data[0] && pkt.Data[0] <= 127)
          {
             // Multi-function (locomotive) decoder, 7 bit address
            sprintf(buffer, "L:%03d ", pkt.Data[0]);
            Serial.print(buffer);          
            decodeMultifunction(&pkt, pkt.Data + 1, pkt.Size - 1);
          }
          else if (192 <= pkt.Data[0] && pkt.Data[0] <= 231)
          {
            uint16_t addr = (uint16_t)pkt.Data[0] & 0x003F;
            addr *= 256;
            addr += pkt.Data[1];
            
            sprintf(buffer, "L:%04d ", addr);
            Serial.print(buffer);
            decodeMultifunction(&pkt, pkt.Data + 2, pkt.Size - 2);
            
          }
          break;
      }
    }
  }
}

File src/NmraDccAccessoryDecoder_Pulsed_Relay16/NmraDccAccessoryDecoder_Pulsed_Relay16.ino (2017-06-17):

#include <NmraDcc.h>
#include "RelayPulser.h"
// This Example shows how to use the library as a DCC Accessory Decoder to drive 8 Pulsed Turnouts


// You can print every DCC packet by un-commenting the line below
//#define NOTIFY_DCC_MSG

// You can print every notifyDccAccTurnoutOutput call-back by un-commenting the line below
#define NOTIFY_TURNOUT_MSG

// You can also print other Debug Messages uncommenting the line below
#define DEBUG_MSG

// Un-Comment the line below to force CVs to be written to the Factory Default values
// defined in the FactoryDefaultCVs below on Start-Up
#define FORCE_RESET_FACTORY_DEFAULT_CV

// Un-Comment the line below to Enable DCC ACK for Service Mode Programming Read CV Capablilty 
#define ENABLE_DCC_ACK  15  // This is A1 on the Iowa Scaled Engineering ARD-DCCSHIELD DCC Shield

#define NUM_TURNOUTS 8              // Set Number of Turnouts (Pairs of Pins)
#define ACTIVE_OUTPUT_STATE HIGH			// Set the ACTIVE State of the output to Drive the Turnout motor electronics HIGH or LOW 

#define DCC_DECODER_VERSION_NUM 11  // Set the Decoder Version - Used by JMRI to Identify the decoder

struct CVPair
{
  uint16_t  CV;
  uint8_t   Value;
};

#define CV_ACCESSORY_DECODER_OUTPUT_PULSE_TIME 2  // CV for the Output Pulse ON ms
#define CV_ACCESSORY_DECODER_CDU_RECHARGE_TIME 3  // CV for the delay in ms to allow a CDU to recharge
#define CV_ACCESSORY_DECODER_ACTIVE_STATE      4  // CV to define the ON Output State 

// To set the Turnout Addresses for this board you need to change the CV values for CV1 (CV_ACCESSORY_DECODER_ADDRESS_LSB) and 
// CV9 (CV_ACCESSORY_DECODER_ADDRESS_MSB) in the FactoryDefaultCVs structure below. The Turnout Addresses are defined as: 
// Base Turnout Address is: ((((CV9 * 64) + CV1) - 1) * 4) + 1 
// With NUM_TURNOUTS 8 (above) a CV1 = 1 and CV9 = 0, the Turnout Addresses will be 1..8, for CV1 = 2 the Turnout Address is 5..12

CVPair FactoryDefaultCVs [] =
{
  {CV_ACCESSORY_DECODER_ADDRESS_LSB,        1},		// CV 1 Board Address (lower 6 bits) 
  {CV_ACCESSORY_DECODER_ADDRESS_MSB,        0},		// CV 9 Board Address (Upper 3 bits)
  {CV_ACCESSORY_DECODER_OUTPUT_PULSE_TIME, 50},   // x 10mS for the output pulse duration
  {CV_ACCESSORY_DECODER_CDU_RECHARGE_TIME, 30},   // x 10mS for the CDU recharge delay time
  {CV_ACCESSORY_DECODER_ACTIVE_STATE,    ACTIVE_OUTPUT_STATE},
};

uint8_t FactoryDefaultCVIndex = 0;

// This is the Relay16 relay number mapping to Turnout Addresses with 2 pins per turnout 
// The Pins are defined in Pairs T=Thrown, C=Closed (Digitrax Notation)  
//   base address 1T 1C 2T 2C 3T 3C 4T  4C  5T  5C  6T  6C  7T  7C  8T  8C
byte outputs[] = { 1, 2, 3, 4, 5, 6, 7, 8, 9, 10, 11, 12, 13, 14, 15, 16 };

NmraDcc  Dcc ;
DCC_MSG  Packet ;
RelayPulser pinPulser;
uint16_t BaseTurnoutAddress;

// This function is called whenever a normal DCC Turnout Packet is received
void notifyDccAccTurnoutOutput( uint16_t Addr, uint8_t Direction, uint8_t OutputPower )
{
#ifdef  NOTIFY_TURNOUT_MSG
  Serial.print("notifyDccAccTurnoutOutput: Turnout: ") ;
  Serial.print(Addr,DEC) ;
  Serial.print(" Direction: ");
  Serial.print(Direction ? "Closed" : "Thrown") ;
  Serial.print(" Output: ");
  Serial.print(OutputPower ? "On" : "Off") ;
#endif
  if(( Addr >= BaseTurnoutAddress ) && ( Addr < (BaseTurnoutAddress + NUM_TURNOUTS )) && OutputPower )
  {
    uint16_t pinIndex = ( (Addr - BaseTurnoutAddress) << 1 ) + Direction ;
    pinPulser.addPin(outputs[pinIndex]);
#ifdef  NOTIFY_TURNOUT_MSG
    Serial.print(" Pin Index: ");
    Serial.print(pinIndex,DEC);
    Serial.print(" Pin: ");
    Serial.print(outputs[pinIndex],DEC);
#endif
  }
#ifdef  NOTIFY_TURNOUT_MSG
  Serial.println();
#endif
}

void initPinPulser(void)
{
  BaseTurnoutAddress = (((Dcc.getCV(CV_ACCESSORY_DECODER_ADDRESS_MSB) * 64) + Dcc.getCV(CV_ACCESSORY_DECODER_ADDRESS_LSB) - 1) * 4) + 1  ;
   
  uint16_t onMs              = Dcc.getCV(CV_ACCESSORY_DECODER_OUTPUT_PULSE_TIME) * 10;
  uint16_t cduRechargeMs     = Dcc.getCV(CV_ACCESSORY_DECODER_CDU_RECHARGE_TIME) * 10;
  uint8_t  activeOutputState = Dcc.getCV(CV_ACCESSORY_DECODER_ACTIVE_STATE);

#ifdef DEBUG_MSG
  Serial.print("initPinPulser: DCC Turnout Base Address: "); Serial.print(BaseTurnoutAddress, DEC);
  Serial.print(" Active Pulse: "); Serial.print(onMs);  
  Serial.print("ms CDU Recharge: "); Serial.print(cduRechargeMs);
  Serial.print("ms Active Output State: "); Serial.println(activeOutputState ? "HIGH" : "LOW" );
#endif  

  // Init the PinPulser with the new settings 
  pinPulser.init(onMs, cduRechargeMs, activeOutputState);
}

void setup()
{
  Serial.begin(115200);

  // Setup which External Interrupt, the Pin it's associated with that we're using and enable the Pull-Up 
  Dcc.pin(0, 2, 1);
  
  // Call the main DCC Init function to enable the DCC Receiver
  Dcc.init( MAN_ID_DIY, DCC_DECODER_VERSION_NUM, CV29_ACCESSORY_DECODER, 0 );

#ifdef DEBUG_MSG
  Serial.print("\nNMRA DCC 8-Turnout Accessory Decoder. Ver: "); Serial.println(DCC_DECODER_VERSION_NUM,DEC);
#endif  

#ifdef FORCE_RESET_FACTORY_DEFAULT_CV
  Serial.println("Resetting CVs to Factory Defaults");
  notifyCVResetFactoryDefault(); 
#endif

  if( FactoryDefaultCVIndex == 0)	// Not forcing a reset CV Reset to Factory Defaults so initPinPulser
	  initPinPulser();  

}

void loop()
{
  // You MUST call the NmraDcc.process() method frequently from the Arduino loop() function for correct library operation
  Dcc.process();
  
  pinPulser.process();

  if( FactoryDefaultCVIndex && Dcc.isSetCVReady())
  {
    FactoryDefaultCVIndex--; // Decrement first as initially it is the size of the array
    uint16_t cv = FactoryDefaultCVs[FactoryDefaultCVIndex].CV;
    uint8_t val = FactoryDefaultCVs[FactoryDefaultCVIndex].Value;
#ifdef DEBUG_MSG
    Serial.print("loop: Write Default CV: "); Serial.print(cv,DEC); Serial.print(" Value: "); Serial.println(val,DEC);
#endif     
    Dcc.setCV( cv, val );
    
    if( FactoryDefaultCVIndex == 0)	// Is this the last Default CV to set? if so re-initPinPulser
	    initPinPulser();
  }
}

void notifyCVChange(uint16_t CV, uint8_t Value)
{
#ifdef DEBUG_MSG
  Serial.print("notifyCVChange: CV: ") ;
  Serial.print(CV,DEC) ;
  Serial.print(" Value: ") ;
  Serial.println(Value, DEC) ;
#endif  

  Value = Value;  // Silence Compiler Warnings...

  if((CV == CV_ACCESSORY_DECODER_ADDRESS_MSB) || (CV == CV_ACCESSORY_DECODER_ADDRESS_LSB) ||
		 (CV == CV_ACCESSORY_DECODER_OUTPUT_PULSE_TIME) || (CV == CV_ACCESSORY_DECODER_CDU_RECHARGE_TIME) || (CV == CV_ACCESSORY_DECODER_ACTIVE_STATE))
		initPinPulser();	// Some CV we care about changed so re-init the PinPulser with the new CV settings
}

void notifyCVResetFactoryDefault()
{
  // Make FactoryDefaultCVIndex non-zero and equal to num CV's to be reset 
  // to flag to the loop() function that a reset to Factory Defaults needs to be done
  FactoryDefaultCVIndex = sizeof(FactoryDefaultCVs)/sizeof(CVPair);
};
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

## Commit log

2015-03-12 Initial grab of a few things to start the schematic
    [ard-dccshield.sch]
2015-03-12 Add modular jack for I2C and push work to date
    [ard-dccshield.sch]
2015-03-12 Add terminal block for external I/O screw attachment
    [ard-dccshield.sch]
2015-03-12 Add selectable power-from-dcc block
    [ard-dccshield.sch]
2015-03-12 End of night updates
    [ard-dccshield.sch]
2015-03-13 Convert all VIO references to just wires with a net attribute rather than the weird supply rail thing that didn't seem to generate correct netlists
    [ard-dccshield.sch]
2015-03-13 Final update to schematic - add ground connection on J2
    [ard-dccshield.sch]
2015-03-13 First cut of completed PCB
2015-03-13 Fixed sliver of ground plane that probably wouldn't have etched well
2015-03-13 Fix border, remove note that doesn't apply
    [ard-dccshield.sch]
2015-03-14 Add BoM, update schematic with note about C2
    [ard-dccshield.sch]
2015-03-15 Add improvements suggested by Arduini list - jumper to power IOREF from +5V, feedback circuit, 4 pin I2C header
    [ard-dccshield.sch]
2015-03-15 Move power connection jumpers from the input to output side of the bridge
    [ard-dccshield.sch]
2015-03-15 Add suggested changes to PCB - feedback circuit, jumper to IOREF, and four pin I2C header
2015-03-15 Add jumpers to turn on/off ack circuit
    [ard-dccshield.sch]
2015-03-15 Add labels to J8 - four pin I2C
2015-03-15 More cleanup - fix R9 refdes, add some more ground plane
    [ard-dccshield.sch]
2015-03-15 Fix DRC issue with bridge rectifier pin clearance
2015-03-15 Update BOM for circuit changes
2015-03-15 Add comment about what the SPI passthrough header is, clarifying that it's not just a spare symbol floating around down there.
    [ard-dccshield.sch]
2015-03-15 Change text silkscreen size to 8mil for better readability
2015-04-08 Change J8 to a through-hole header for end user assembly. Move some silkscreen around
    [ard-dccshield.sch]
2015-04-08 Change LEDs to 0805
    [ard-dccshield.sch]
2015-04-08 Add PG for v1.0 to send for manufacturing
    [ard-dccshield.bottom.gbr, ard-dccshield.bottommask.gbr, ard-dccshield.bottompaste.gbr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]
2015-04-08 Update BOM for latest changes to the board - 0805 LEDs, through hole version of J8
2015-05-11 Fixes with issues in v1.0 of the ARD-DCCSHIELD Footprint for bridge rectifier was wrong + was on wrong end of DCC indicator LED
    [ard-dccshield.sch]
2015-05-18 Fix issues with v1.0 ard shield - fix BR pinout, fix LED + sign
    [ard-dccshield.bottom.gbr, ard-dccshield.bottommask.gbr, ard-dccshield.bottompaste.gbr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]
2015-09-07 Fixed SDA/SCL text on 4-pin header
2015-10-19 Add gitignore Modify R3 to 330 ohm Update BOM
    [ard-dccshield.sch]
2015-10-19 Add pg of 1.2 (silkscreen fix for SDA/SCL on 4-pin I2C header)
    [ard-dccshield.bottom.gbr, ard-dccshield.bottommask.gbr, ard-dccshield.bottompaste.gbr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]
2015-10-20 Board image
2016-03-14 Sketch for testing the boards
2016-03-14 Commented out SDA/SCL code that didn't work.
    [dccshield_test.ino]
2016-03-14 Fixed I2C test code
    [dccshield_test.ino]
2016-03-14 Added comments for the hardware needed to test the board.
2016-09-15 Change some resistors to rpacks, increment version. Fix github issues #1, #2, #3
    [ard-dccshield.sch]
2016-11-01 New pg version to get rid of some of the discrete resistors
    [ard-dccshield.bottom.gbr, ard-dccshield.bottommask.gbr, ard-dccshield.bottompaste.gbr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]
2017-06-06 Example to use Alex Shepherd's NmraDccAccessoryDecoder_Pulsed with the relay16 as an output stage
2017-06-06 Add on/off variety of the relay16 shield code
2017-06-16 Remove pulse configuration code that's no longer relevant
    [NmraDccAccessoryDecoder_Relay16.ino]
2017-09-11 Fixed missing components in schematic
2017-10-06 Update the readme to be a bit clearer and give links to the various schematic versions
2022-04-18 Initial cut of new schematic
    [ard-dccshield.sch]
2022-04-24 First cut of v2 PCB
    [ard-dccshield.sch]
2022-05-15 Sent to fab 5/14/2022
    [ard-dccshield.bottom.gbr, ard-dccshield.bottommask.gbr, ard-dccshield.bottompaste.gbr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]
